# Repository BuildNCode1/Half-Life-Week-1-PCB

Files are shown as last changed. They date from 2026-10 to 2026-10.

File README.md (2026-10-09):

# Unghost
> A pocket-sized reminder device that nudges you to reach out to the people you haven't talked to in a while.

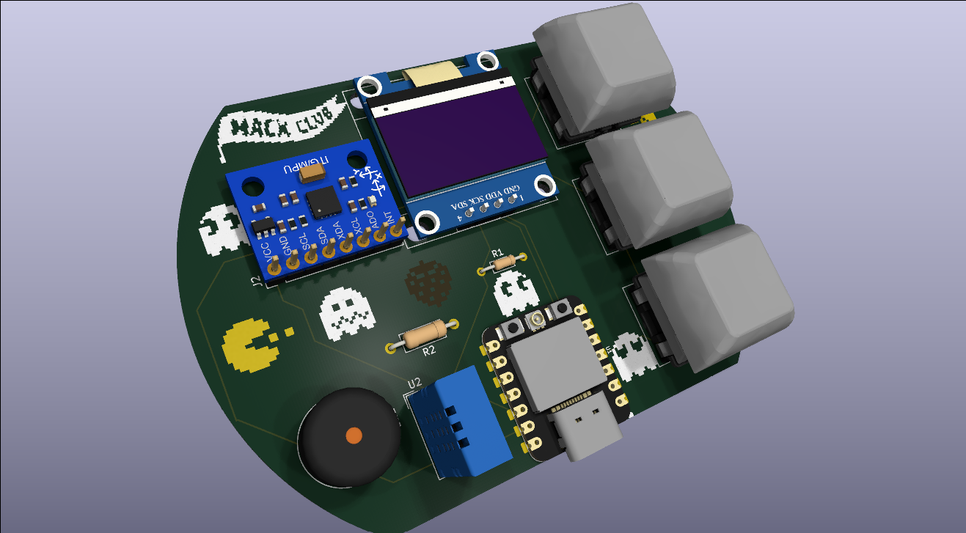
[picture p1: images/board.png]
Render of Finished Board


## Why I made this
Isolation is too common in today's culture. With everyone rushing to the next task of a busy life, everyday human contact can be left all but forgotten. This little guy fixes that, and makes keeping in touch harder to forget.

## What it does

- Tracks how long it's been since you contacted each person
- Chimes with a little "waka waka" when someone is overdue
- Shows the contacts, days since last contact, and a "Call (So and Such)!" banner on an OLED
- Three buttons: **Next contact**, **I contacted them**, **Snooze**
- Shows room temperature and humidity
- *(PLANNED)* Syncs contacts and time from your phone over Bluetooth LE

## Hardware

| Part | Purpose |
|---|---|
| Seeed XIAO ESP32-C3 | Microcontroller with built-in BLE |
| 0.96" SSD1306 OLED (I2C) | Display |
| MPU6050 breakout | Motion sensing (PLANNED: tap/flip to snooze) |
| DHT11 | Temperature and Humidity |
| Passive piezo buzzer | Reminder chimes |
| 3× Cherry MX Switches | User Input |
| 10 kΩ resistor (R1) | DHT11 data pull-up |
| 100 Ω resistor (R2) | Buzzer series resistor |

## Pinout
| XIAO Pin | Connected to |
|---|---|
| D1 | DHT11 data |
| D2 | SW1 (next contact) |
| D3 | SW2 (I contacted them) |
| D4 | SW3 (snooze) |
| D5 | I2C SCL |
| D6 | I2C SDA |
| D10 | Buzzer (via 100 Ω) |

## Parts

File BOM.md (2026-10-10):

# Starbie – bill of materials

<!-- Generated by Half Life from project cmuvet90l00e301rvsyj1wp4x. Edits here are overwritten on the next sync. -->
<!-- Generated: 2026-10-10T14:32:49.808Z -->

> [!NOTE]
> This parts list is mirrored from [Half Life](https://halflife.hackclub.com). Editing it here will not change the platform's copy, and the next sync overwrites this file.

| Week | Tier | Parts funding |
| --- | --- | --- |
| Week 1 | Tier 1 | $30.00 |

| Part | What it's for | Qty | Unit | Total | Vendor |
| --- | --- | --- | --- | --- | --- |
| [Seeed XIAO ESP32-C3](https://www.seeedstudio.com/Seeed-XIAO-ESP32C3-p-5431.html) | Microcontroller with built-in BLE | 1 | $4.99 | $4.99 | [Seeed Studio](https://www.seeedstudio.com/Seeed-XIAO-ESP32C3-p-5431.html) |
| [0.96" SSD1306 OLED (I2C)](https://www.aliexpress.us/item/3256807526105550.html?src=google&gatewayAdapt=glo2usa) | Display | 1 | $1.09 | $1.09 | [AliExpress](https://www.aliexpress.us/item/3256807526105550.html?src=google&gatewayAdapt=glo2usa) |
| [MPU6050 breakout](https://www.aliexpress.us/item/3256809542137777.html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) | Motion Sensing | 1 | $1.09 | $1.09 | [AliExpress](https://www.aliexpress.us/item/3256809542137777.html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) |
| [DHT11 (4pin pls)](https://www.aliexpress.us/item/3256807449697831.html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) | Temperature and Humidity | 1 | $1.57 | $1.57 | [AliExpress](https://www.aliexpress.us/item/3256807449697831.html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) |
| [Passive Piezo Buzzer](https://www.aliexpress.us/item/3256808937377909.html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) | Reminder Chimes | 1 | $1.09 | $1.09 | [AliExpress](https://www.aliexpress.us/item/3256808937377909.html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) |
| [MX Switches (8pk from AliExpress)](https://www.aliexpress.us/item/2255800623836900.html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) | User Input | 1 | $1.09 | $1.09 | [AliExpress](https://www.aliexpress.us/item/2255800623836900.html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) |
| [10 kΩ resistor (100pk bcs they always come in freaking bundles)](https://www.aliexpress.us/item/3256807353528247.html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) | DHT11 data pull-up | 1 | $1.09 | $1.09 | [AliExpress](https://www.aliexpress.us/item/3256807353528247.html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) |
| [100 Ω resistor (again 100pk freaking bundle)](https://www.aliexpress.us/item/3256803900148387.html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) | Buzzer Series Resistor | 1 | $1.01 | $1.01 | [AliExpress](https://www.aliexpress.us/item/3256803900148387.html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) |
| **Parts subtotal** | — | — | — | **$13.02** | — |
| **Tax & shipping** | — | — | — | **$0.00** | — |
| **Total** | — | — | — | **$13.02** | — |

$16.98 left of the tier's funding.

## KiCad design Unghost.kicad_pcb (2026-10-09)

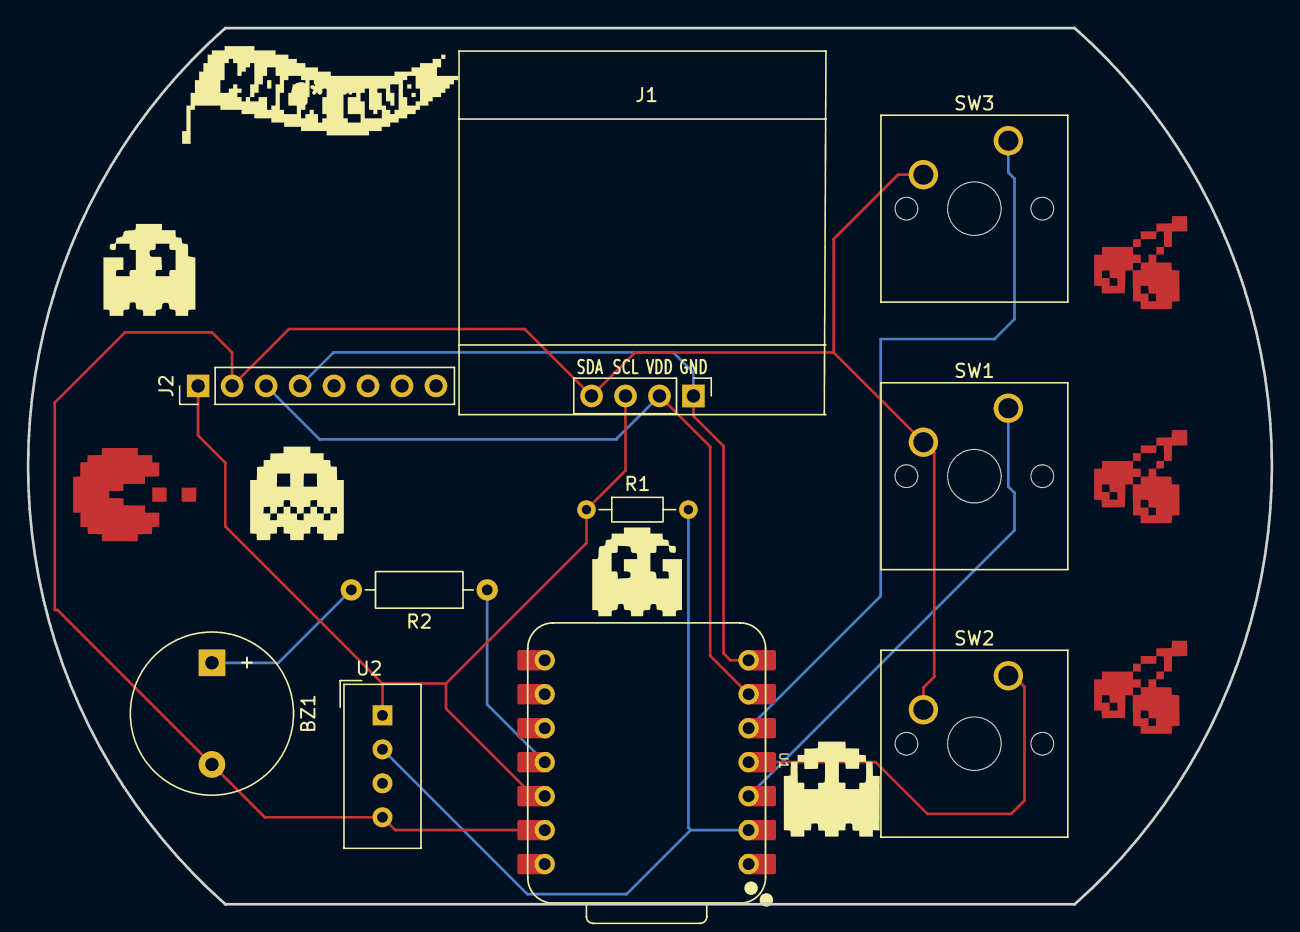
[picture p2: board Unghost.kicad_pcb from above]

Board: 2 copper layers, 93.0 x 65.5 mm, 10 parts (0 on the bottom side), 10 nets.

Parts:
BZ1: Buzzer; Buzzer_12x9.5RM7.6
J1: Conn_01x04_Pin; Display_128x64_096_I2C
J2: Conn_01x08_Pin; PinHeader_1x08_P2.54mm_Vertical
R1: 10k; R_Axial_DIN0204_L3.6mm_D1.6mm_P7.62mm_Horizontal
R2: 100Ω; R_Axial_DIN0207_L6.3mm_D2.5mm_P10.16mm_Horizontal
SW1, SW2, SW3: SW_Push; SW_Cherry_MX_1.00u_PCB
U1: XIAO-ESP32-C3-SMD; XIAO-ESP32-C6-DIP
U2: DHT11; Aosong_DHT11_5.5x12.0_P2.54mm

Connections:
+3.3V: J1.3, J2.1, R1.1, U1.12 (3V3_OUT), U2.1 (VDD)
/DHT11 DATA: R1.2, U1.2 (D1), U2.2 (DATA)
/GP102: SW1.1, U1.3 (D2)
/GP103: SW2.1, U1.4 (D3)
/GP104: SW3.1, U1.5 (D4)
/GP1010: R2.1, U1.11 (D10)
/SCL: J1.2, J2.3, U1.6 (D5)
/SDA: J1.1, J2.4, U1.7 (D6)
GND: BZ1.2 (-), J1.4, J2.2, SW1.2, SW2.2, SW3.2, U1.13 (GND), U2.4 (GND)
unnamed: BZ1.1 (+), R2.2

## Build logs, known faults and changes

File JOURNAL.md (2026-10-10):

# Starbie – devlog

<!-- Generated by Half Life from project cmuvet90l00e301rvsyj1wp4x. Edits here are overwritten on the next sync. -->
<!-- Generated: 2026-10-10T17:43:18.933Z -->

> [!NOTE]
> This devlog is mirrored from [Half Life](https://halflife.hackclub.com). Editing it here will not change the platform's copy, and the next sync overwrites this file.

> A tiny motion-controlled digital pet, basically a desktop Tamagotchi. Totally not a Starboy.

| Week | Tier | Hours logged | Entries |
| --- | --- | --- | --- |
| Week 1 | Tier 1 | 9.02h | 5 |

## Contents

1. [2026-10-05 – Work session](#2026-10-05-work-session)
2. [2026-10-06 – Work session](#2026-10-06-work-session)
3. [2026-10-06 – Work session](#2026-10-06-work-session)
4. [2026-10-09 – Work session](#2026-10-09-work-session)
5. [2026-10-10 – Work session](#2026-10-10-work-session)

## Design

### 2026-10-05 – Work session

**1.9h**

[Timelapse](https://lookout.hackclub.com/api/media/554ffd1d-4ef2-4aeb-a8f7-398b35392957/video.mp4)

### 2026-10-06 – Work session

**1.03h**

[Timelapse](https://lookout.hackclub.com/api/media/dbe3e4ba-e116-448b-a03e-e2223b126ce7/video.mp4)

### 2026-10-06 – Work session

**1.17h**

[Timelapse](https://lookout.hackclub.com/api/media/c691f5b2-082f-4253-9714-dc90463ed97a/video.mp4)

### 2026-10-09 – Work session

**2.37h**

[Timelapse](https://lookout.hackclub.com/api/media/6141e4ce-9ed8-4c7c-b00b-6ade674687f2/video.mp4)

### 2026-10-10 – Work session

**2.55h**

[Timelapse](https://lookout.hackclub.com/api/media/1b8f5e88-ad48-4b9a-8cbf-92bb0c6154cc/video.mp4)

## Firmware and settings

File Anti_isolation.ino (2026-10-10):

#include <Wire.h>
#include <Adafruit_GFX.h>
#include <Adafruit_SSD1306.h>
#include <DHT.h>

#define PIN_DHT    D1
#define PIN_BTN_1  D2
#define PIN_BTN_2  D3
#define PIN_BTN_3  D4
#define PIN_SCL    D5
#define PIN_SDA    D6
#define PIN_BUZZER D10

#define SECONDS_PER_DAY   10UL
#define SNOOZE_MS         60000UL
#define CHIME_REPEAT_MS   15000UL
#define DEBOUNCE_MS       30

#define MPU_ADDR          0x68
#define TILT_DEBUG        1

#define TILT_LR_AXIS      ay
#define TILT_LR_SIGN      1
#define FLIP_SIGN         1

#define TILT_ON_G         0.45f
#define TILT_OFF_G        0.20f
#define FACE_DOWN_G       0.75f
#define FLIP_HOLD_MS      600

Adafruit_SSD1306 display(128, 64, &Wire, -1);
DHT dht(PIN_DHT, DHT11);

struct Contact {
  const char* name;
  uint16_t remindAfterDays;
  uint32_t lastContactMs;
};

Contact contacts[] = {
  {"Mom",      3,  0},
  {"Dad",      7,  0},
  {"Liam",     14, 0},
};
const int NUM_CONTACTS = sizeof(contacts) / sizeof(contacts[0]);

struct Button {
  uint8_t pin;
  bool lastState;
  uint32_t lastChangeMs;
};

Button btnNext   = {PIN_BTN_1, HIGH, 0};
Button btnDone   = {PIN_BTN_2, HIGH, 0};
Button btnSnooze = {PIN_BTN_3, HIGH, 0};

bool wasPressed(Button &b) {
  bool now = digitalRead(b.pin);
  if (now != b.lastState && (millis() - b.lastChangeMs) > DEBOUNCE_MS) {
    b.lastChangeMs = millis();
    b.lastState = now;
    if (now == LOW) return true;
  }
  return false;
}

int selected = 0;
uint32_t snoozeUntilMs = 0;
uint32_t lastChimeMs = 0;
uint32_t lastDhtMs = 0;
float tempC = NAN;
float humidity = NAN;

bool mpu0k = false;
float ax = 0, ay = 0, az = 0;
bool tiltArmed = true;
uint32_t faceDownSinceMs = 0;
bool flipHandled = false;

void beep (int freq, int ms) {
  ledcWriteTone(PIN_BUZZER, freq);
  delay(ms);
  ledWriteTone(PIN_BUZZER, 0);
}

void chime () {
  beep (880, 120); delay (40);
  beep (1175, 120); delay (40);
  beep(1568, 250);
}

bool mpuInit() {
  Wire.beginTransmission(MPU_ADDR);
  Wire.write(0x68);
  Wire.write(0x00);
  if (Wire.endTransmission() != 0) return false;

  Wire.beginTransmission(MPU_ADDR);
  Wire.write(0x1C);
  Wire.write(0x00);
  return Wire.endTransmission() == 0;
}

int16_t read16() {
  uint8_t hi = Wire.read();
  uint8_t lo = Wire.read();
  return (int16_t)(hi << 8 | lo)
}

bool readAccel() {
  Wire.beginTransmission(MPU_ADDR);
  Wire.write(0x3B);
  if(Wire.endTransmission(false) != 0) return false;
  if (Wire.requestFrom((uint8_t)MPU_ADDR, (uint8_t)6) != 6) return false;
  ax = read16() / 16384.0f;
  ay = read16() / 16384.0f;
  az = read16() / 16384.0f;
  return true;
}

void snooze() {
  snoozeUntilMs = millis() + SNOOZE_MS;
  beep(660, 80);
}

void changeContact(int dir) {
  selected = (selected + dir + NUM_CONTACTS) % NUM_CONTACTS;
}

void updateTilt() {
  if (!mpu0k) return;

  static uint32_t lastReadMs = 0;
  if (millis() - lastReadMs < 20) return;
  lastReadMs = millis
  if (!readAccel()) return;

#if TILT_DEBUG
  static uint32_t lastPrintMs = 0;
  if(millis() - lastPrintMs > 250) {
    lastPrintMs = millis();
    Serial.printf("ax=%.2f ay=%.2f, az=%.2f\n" ax, ay, az);
  }
#endif

  bool faceDown = (FLIP_SIGN * az) < -FACE_DOWN_G;
  if (faceDown) {
    if (faceDownSinceMs == 0) faceDownSinceMs = millis();
    if (!flipHandled && (millis() - faceDownSinceMs) > FLIP_HOLD_MS) {
      snooze();
      flipHandled = true;
    }
  } else {
    faceDownSinceMs = 0;
    flipHandled = false;
  }
  
  if (!faceDown) {
    float lr = TILT_LR_SIGN * TILT_LR_AXIS;
    if (tiltArmed) {
      if (lr > TILT_ON_G) {
        changeContact(+1);
        tiltArmed = false;
        beep(2000, 15);
      } else if (lr < -TILT_ON_G) {
        changeContact(-1);
        tiltArmed = false;
        beep(2000, 15);
      }
    } else if (fabsf(lr) < TILT_OFF_G) {
      tiltArmed = true;
    }
  }
}

uint32_t daysSince(const Contact &c) {
  return (millis() - c.lastContactMs) / (1000UL * SECONDS_PER_DAY)
}

int overdueIndex() {
  for (int i = 0;  i< NUM_CONTACTS; i++) {
    if (daysSince(contacts[i]) >= contacts[i].remindAfterDays) return i;
  }
  return -1
}

void readSensor() {
  if(millis() - lastDhtMs < 2000) return;
  lastDhtMs = millis();
  float t = dht.readTemperature();
  float h = dht.readHumidity();
  if (!isnan(t)) tempC = t;
  if (!isnan(h)) humidity = h;
}

void drawScreen(int dueIdx, bool snoozed) {
  const Contact &c = contacts[selected];
  display.clearDisplay();
  display.setTextColor(SSD1306_WHITE);
  display.setTextSize(2);
  display.setCursor(0, 0);
  display.print(c.name);
  display.setTextSize(1);
  display.setCursor(0, 20);
  display.printf("Last: %lu days ago", (unsigned long)daysSince(c));
  display.setCursor(0, 30);
  display.printf("Remind every %d days", (int)c.remindAfterDays);

  display.setCursor(0, 42);
  if(isnan(tempC) || isnan(humidity)) {
    display.print("Temp: --");
  } else {
    display.print ("%.0fC  %.0f%% RH", tempC, humidity);
  }

  display.setCursor(0, 54);
  if (dueIdx >= 0)  {
    if (snoozed) display.print ("Snoozed...");
    else display.printf("Call %s!", contacts[dueIdx].name);
  }
  display.display();
}

void setup() {
  Serial.begin(115200)

  pinMode(PIN_BTN_1, INPUT_PULLUP);
  pinMode(PIN_BTN_2, INPUT_PULLUP);
  pinMode(PIN_BTN_3, INPUT_PULLUP);

  Wire.begin(PIN_SDA, PIN_SCL);
  Wire.setClock(400000);

  if (!display.begin(SSD1306_SWITCHCAPVCC, 0x3C)) {
    Serial.println("OLED not found, check SDA/SCL wiring");
  }

  mpu0k = mpuInit();
  if (!mpu0k) Serial.println("MPU6050 not found at 0x68 - tilt disabled");

  dht.begin();
  ledcAttach(PIN_BUZZER, 2000, 8);

  for (int i = 0; i < NUM_CONTACTS; i++) contacts[i].lastContactMs = millis();

  beep(1568, 100)
}

void loop() {
  if (wasPressed(btnNext)) {
    selected = (selected + 1) % NUM_CONTACTS;
  }
  if(wasPressed(btnDone)) {
    contacts [selected].lastContactMs = millis();
    beep (1568, 80);
  }
  if(wasPressed(btnSnooze)) {
    snoozeUntilMs = millis() + SNOOZE_MS;
    beep (660, 80);
  }

  updateTilt();

  readSensor();

  bool snoozed = (int32_t)(snoozeUntilMs - millis()) > 0;
  int due = overdueIndex();
  if (due >= 0 && !snoozed && (millis() - lastChimeMs) > CHIME_REPEAT_MS) {
    chime();
    lastChimeMs = millis;
  }
  
  drawScreen(due, snoozed);
}

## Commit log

2026-10-11 Add image render of finished case to README
2026-10-19 Update JOURNAL.md with recent work sessions
    Documented work sessions detailing progress on schematic, coding, and board design.
